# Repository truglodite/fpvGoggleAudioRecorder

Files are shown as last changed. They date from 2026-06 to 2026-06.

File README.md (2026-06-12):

# fpvGoggleAudioRecorder
## A reliable audio recording device for FPV goggles

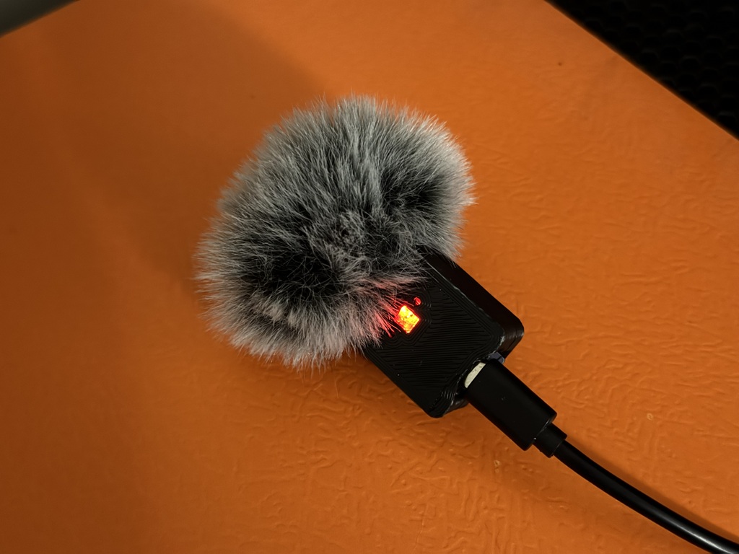
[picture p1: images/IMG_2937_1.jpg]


This is code for a plug and forget ambient audio recorder, intended for use with FPV goggles (like DJI goggles).

### Hardware:
*No pins installed if using the printable enclosure*
- Waveshare RP2040 Zero: https://www.amazon.com/DWEII-RP2040-Zero-Microcontroller-Development-MicroPython/dp/B0C5Q2V49P
- ICS43434 I2S Microphone: https://www.amazon.com/ICS43434-Microphone-Breakout-Module-Filter/dp/B0FMDGRM8F
- Micro SD Card Breakout (3.3V): https://www.amazon.com/WWZMDiB-Module-Adapter-Memory-Shield/dp/B0BV8ZQ81F
- 6mm Momentary NO Tactile Button: https://www.amazon.com/Momentary-Tactile-Through-Breadboard-Friendly/dp/B07WF76VHT

* Note that an INMP441 mic could be used in place of the ICS43434 if needed, but audio quality is not quite as good. Also the printed enclosure only fits the ICS mic.

### Operation
Simply plug in USB power, and the system will start to record. Unplug USB to stop the recording. If you need to start a new file during a recording session, hit the button, a blue LED will flash, and a new file will be started. This can be useful if for example you wait a while for GPS before launching, hit the button so you have an audio file that starts just before launching.

When powering on, you should first see a blue LED to indicate boot status followed by a pulsating green LED to indicate normal recording, and with an occasional red flash during louder noises to indicate the clipping limiter is active. If you see just a repeating flashing red led, the SD card is failing. If you see an orange flashing LED, the audio buffer is falling behind.

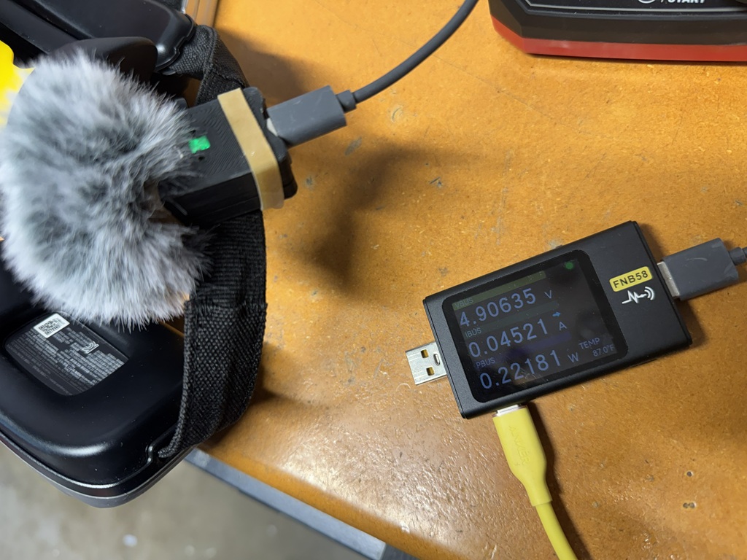
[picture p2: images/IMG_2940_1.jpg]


The goggle battery should be more than adequate even for very long flying sessions. The circuit draws only ~50mA while recording.

### Recording Format:
Similar to how a dashcam/bodycam works, this code records audio to raw PCM files with routines that prevent data corruption when power is suddenly lost while recording. When power is cutoff, only the last seconds of the recording session will be lost. The files are named "rec_X-Y.raw", where X is the recording session, and Y is the audio segment. Both X and Y increment to allow easy reconstruction of wav files. The "manifest.txt" file keeps a log of segments that have been saved, as well as segments that were lost due to power cutoff. The newest segments will be at the top of the manifest file.

The code makes use of an RMS audio compressor with smooth clipping that has been somewhat optimized for the hardware and intended application. Voices and noises farther away will have a similar volume to the voice of the person wearing the mic. Due to "aggressive AGC parameters", there will be some noise underlying the audio, but it is minimal. The audio performance with the ICS43434 using approach results much higher quality audio compared to the usual MAX9815+ADC setup.

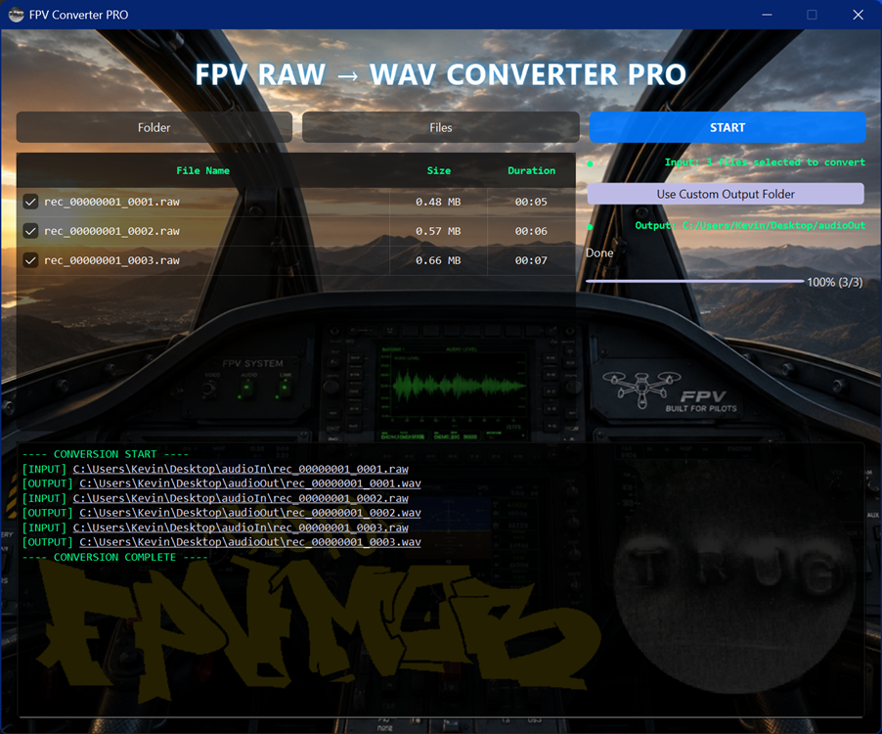
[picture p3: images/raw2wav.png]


For convenience I created `raw2wav.exe`, a Windows executable that converts raw files recorded with the fpvGoggleAudioRecorder into easy to use wav files (raw2wav.exe, in raw2wav/dist/). To use the converter, run the `raw2wav.exe`, select the input folder (your SD card) and optionally an output folder. If any of the loaded files do not need conversion, uncheck the box next to them in the file selector area. Click the "Start" button to convert the selected files. The log area near the bottom shows which files are being converted and where the converted files are saved. You can click an output path in the log area to open the output folder in explorer.

Alternatively, you can use an audio editing program like Audacity to "import raw data", with "little endian" and "44000" bit rate, and export a wav file.

### Flashing/Compiling:
To flash your RP2040 with the included firmware (`.pio/build/pico/firmware.uf2`), hold the boot button then press/release the reset button to put the board into flashing mode. The RP2040 should show up as a mass storage device in explorer. Simply copy `firmware.uf2` to the root of the RP2040, and reboot.

If you would like to customize the code, you should import this repo to PlatformIO. The maxgerhardt raspi platform, the earlephilhower pico core, and the Adafruit NeoPixel library are required for compiling.

https://github.com/maxgerhardt/platform-raspberrypi.git
https://github.com/earlephilhower/arduino-pico

### Wiring:
Connect the hardware as shown in the table below. The button is optional for manual recording variants, and is not required for autorecording.

Device  |   Pin |   RP2040 Pin
----|-----|----
MIC |   SEL |   GND
MIC |   LRCL |   11
MIC |   DOUT |   12
MIC |   BCLK |   10
MIC |   GND |   GND
MIC |   3V |   3v3
SD |   GND |   GND
SD |   MISO |   4
SD |   CLK |   2
SD |   MOSI |   3
SD |   CS |   5
SD |    3v3 |   3v3
BUTT |   A/B |   6/GND

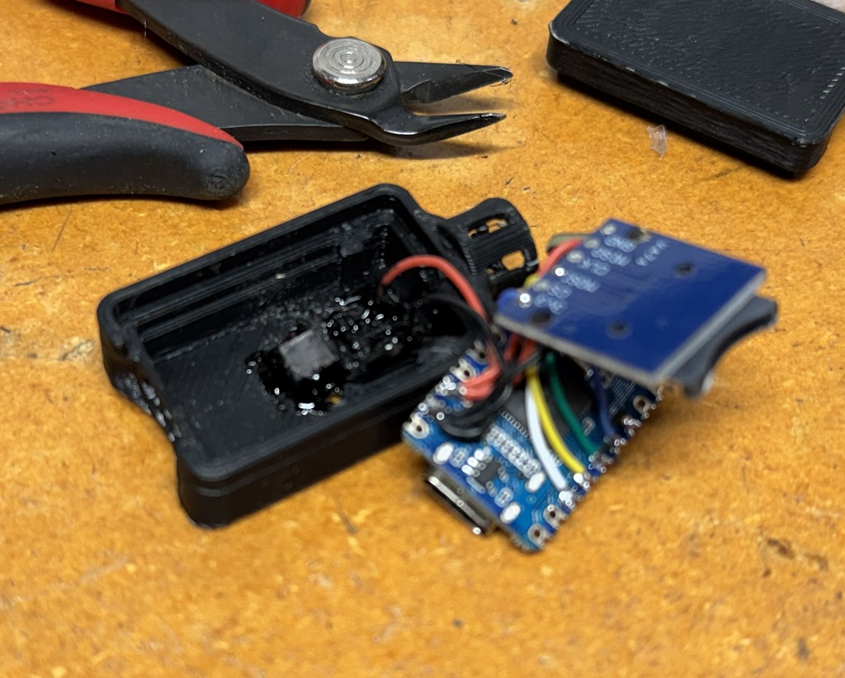
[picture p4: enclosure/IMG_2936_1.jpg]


### Printable Enclosure:
Files for a printable enclosure are provided in this repo. One of each part should be printed. Print the "agcRecorderTopWindscreen.stl" if you want to use a 10mm foam or furry cover for the mic. ABS or PETG is recommended for the top, bottom, and shim. Clear PETG filament should be used for the lens. Some glue is needed for a durable assembly; I used T-7000 glue on all of the joints described below.

To assemble the enclosure, first test fit your button, boards, and mic in the enclosure top/bottom. The mic is oriented with pin holes toward the top, with the mic hole facing out the side with the hole in it. The RP2040 is inserted with buttons facing the top, USB out the side. The button is rotated with pin sides facing the mic/usb sides of the enclosure. The SD card board is placed with the metal card insert part facing toward the top. First insert the lens, button, and mic in the top half, then insert the RP2040 board. Insert the SD board in the bottom half. Place the board shim over the RP2040 processor, and press the bottom half onto the top half. There are tabs for a click fit between the top/bottom halves. When assembled, verify the button protrudes out the top enough for easy operation, the SD card is easy to insert/remove, USB cable is easy to get to, and the case halves close completely. There should be an even 1mm gap around the edge where the top/bottom halves fit together. Also make sure you can fit a paper clip or similar rod through the Boot/Reset button access holes located near the lens.

The enclosure is very compact; 30awg silicone wire or smaller is recommended. Make all wires long enough to reach when assembled, but not so long that assembly can pinch a wire. Leave enough length on the SD card wires so the enclosure halves can easily be assembled/disassembled. Solder wires for the button and add heatshrink; break off the unused pins from the other side of the button. Solder wires to the chip side of the microphone. Solder wires to the back side (opposite of boot/reset buttons) on the RP2040. When wires are all soldered, glue the button into place taking care not to allow glue to squirt where it may interfere with operation. Glue the lens into the top half of the case. Add glue to the rails where the RP2040 and SD card boards will rest, and insert the components into the case halves. Snap case halves together taking care not to pinch any wires. Add the windscreen cover if desired; some glue around the bottom of the windstopper basket where it touches the box will offer a more reliable hold.

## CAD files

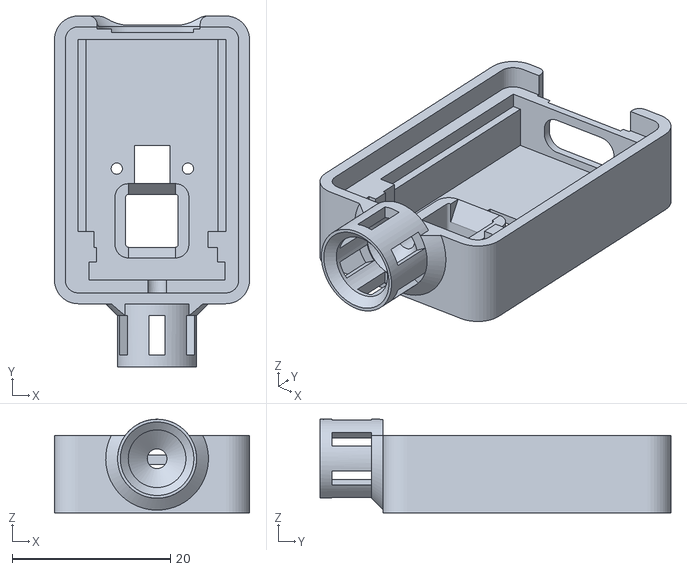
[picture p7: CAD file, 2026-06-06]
enclosure/agcRecorderTopWindscreen.stl
24.7 x 44.4 x 11.8

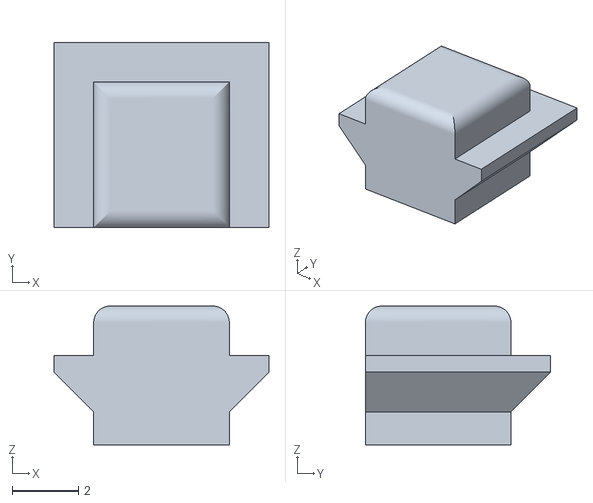
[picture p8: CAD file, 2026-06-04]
enclosure/agcRecorderLens.stl
6.50 x 5.60 x 4.20

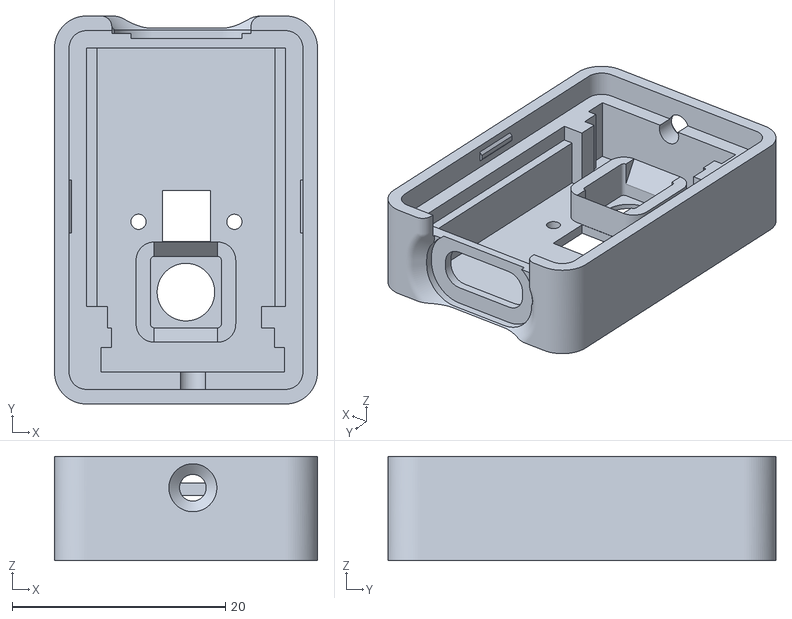
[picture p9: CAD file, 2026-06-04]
enclosure/agcRecordertop.stl
24.7 x 36.4 x 9.79

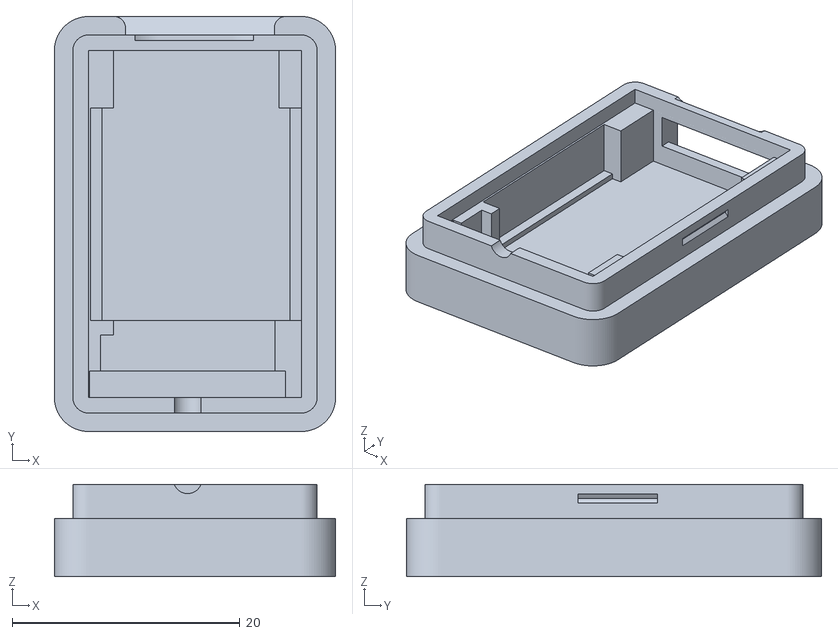
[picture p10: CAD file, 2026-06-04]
enclosure/agcRecorderBottom.stl
24.7 x 36.4 x 8.08

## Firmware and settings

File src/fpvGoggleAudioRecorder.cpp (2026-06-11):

/*
    fpvGoggleAudioRecorder.cpp
    Production-oriented FPV goggle audio recorder

    Hardware:
    - Waveshare RP2040 Zero
    - ICS43434 I2S microphone
    - SPI microSD
    - Momentary Segment Button on GPIO 6 (Active Low, Internal Pullup)

    Features:
    - Dual-core audio pipeline
    - Large ring buffer
    - Crash-resistant segmented recording
    - SD write retries
    - Core1 heartbeat monitoring
    - I2S timeout recovery
    - Queue synchronization barriers
    - Disk full detection
    - Watchdog recovery
    - Non-blocking LED updates with visual button feedback
    - Instant power-on recording
    - Manual file split / start new file button (GPIO 6)

    Audio:
    - RAW PCM
    - Signed 16-bit little endian
    - 44100 Hz mono

    Requires:
    - Arduino-Pico (Earle Philhower)
*/

#include <Arduino.h>
#include <SPI.h>
#include <SD.h>
#include <I2S.h>
#include <Adafruit_NeoPixel.h>

#include "pico/multicore.h"
#include "hardware/watchdog.h"
#include "hardware/sync.h"

#include <math.h>

// ======================================================
// CONFIG
// ======================================================

#define SAMPLE_RATE            44100

#define BLOCK_SAMPLES          256
#define QUEUE_BLOCKS           128

#define SEGMENT_MS             120000UL
#define FLUSH_INTERVAL_MS      1000UL

#define SD_CS                  5
#define LED_PIN                16
#define BUTTON_PIN             6  // New File / Split Button on GPIO 6

#define I2S_DATA_PIN           12
#define I2S_BCLK_PIN           10

#define WATCHDOG_TIMEOUT_MS    4000
#define CORE1_TIMEOUT_MS       2000

#define MEMORY_BARRIER()       __dmb()

// ======================================================
// LED
// ======================================================

Adafruit_NeoPixel led(
    1,
    LED_PIN,
    NEO_GRB + NEO_KHZ800
);

enum LedMode
{
    LED_BOOT,
    LED_RECORDING,
    LED_SD_WARN,
    LED_BUFFER_WARN,
    LED_FATAL,
    LED_BUTTON_SPLIT // Added: State for button press feedback
};

volatile LedMode ledMode = LED_BOOT;
volatile uint32_t buttonFeedbackStartMs = 0; // Tracks when the blue LED turned on

// ======================================================
// SHARED STATE
// ======================================================

volatile uint16_t globalPeak = 0;
volatile uint32_t lastAudioMs = 0;

volatile uint32_t core1Heartbeat = 0;

volatile bool fatalState = false;
volatile bool sdWarning = false;
volatile bool bufferWarning = false;
volatile bool diskFull = false;

volatile bool recording = false;
volatile bool rolloverPending = false;
volatile bool limiterActive = false;

// ======================================================
// I2S
// ======================================================

I2S i2s(INPUT);

// ======================================================
// AUDIO BUFFER
// ======================================================

enum BlockState : uint8_t
{
    BLOCK_FREE = 0,
    BLOCK_FILLED = 1
};

struct AudioBlock
{
    int16_t samples[BLOCK_SAMPLES];
    volatile BlockState state;
};

AudioBlock queueBuffer[QUEUE_BLOCKS];

volatile uint16_t writeIndex = 0;
volatile uint16_t readIndex  = 0;

// ======================================================
// FILES
// ======================================================

File audioFile;
File manifestFile;

char currentFilename[64];

uint32_t sessionId = 0;
uint32_t segmentId = 0;

// ======================================================
// SYSTEM HEALTH
// ======================================================

struct SystemHealth
{
    volatile uint32_t bufferOverruns = 0;
    volatile uint32_t i2sTimeouts    = 0;
    volatile uint32_t sdErrors       = 0;
    volatile uint32_t writes         = 0;
};

SystemHealth sys;

// ======================================================
// LED HELPERS
// ======================================================

void setLED(
    uint8_t r,
    uint8_t g,
    uint8_t b
)
{
    led.setPixelColor(
        0,
        led.Color(r, g, b)
    );

    led.show();
}

void updateLedState()
{
    if (fatalState)
    {
        ledMode = LED_FATAL;
        return;
    }

    if (diskFull)
    {
        ledMode = LED_FATAL;
        return;
    }

    // Prioritize showing the blue button flash if it's currently active
    if (ledMode == LED_BUTTON_SPLIT)
    {
        if ((millis() - buttonFeedbackStartMs) < 500) 
        {
            return; // Stay in blue flash mode for 500ms
        }
    }

    if (sdWarning)
    {
        ledMode = LED_SD_WARN;
        return;
    }

    if (bufferWarning)
    {
        ledMode = LED_BUFFER_WARN;
        return;
    }

    ledMode = LED_RECORDING;
}

void updateLED()
{
    static uint32_t lastUpdate = 0;

    if ((millis() - lastUpdate) < 50)
        return;

    lastUpdate = millis();

    switch (ledMode)
    {
        case LED_BOOT:
        {
            setLED(0, 0, 40);
            break;
        }

        case LED_FATAL:
        {
            static bool blink = false;

            blink = !blink;

            if (blink)
                setLED(0, 100, 0);
            else
                setLED(0, 0, 0);

            break;
        }

        case LED_SD_WARN:
        {
            static bool blink = false;

            blink = !blink;

            if (blink)
                setLED(0, 80, 0);
            else
                setLED(0, 0, 0);

            break;
        }

        case LED_BUFFER_WARN:
        {
            static bool blink = false;

            blink = !blink;

            if (blink)
                setLED(40, 80, 0);
            else
                setLED(0, 0, 0);

            break;
        }

        case LED_BUTTON_SPLIT:
        {
            // Turn LED Solid Blue for file split confirmation
            setLED(0, 0, 120); 
            break;
        }

        case LED_RECORDING:
        {
            bool active =
                (
                    millis() -
                    lastAudioMs
                ) < 250;

            if (!active)
            {
                setLED(
                    0,
                    2,
                    0
                );
            }
            else
            {
                uint8_t level =
                    constrain(
                        map(
                            globalPeak,
                            0,
                            16000,
                            2,
                            80
                        ),
                        2,
                        80
                    );

                // Clip indicator
                if (
                    limiterActive
                )
                {
                    setLED(
                        0,
                        80,
                        0
                    );
                }
                else
                {
                    // Audio level meter
                    setLED(
                        level,
                        0,
                        0
                    );
                }
            }

            break;
        }
    }
}

// ======================================================
// FATAL HANDLER
// ======================================================

void fatalError()
{
    fatalState = true;

    while (1)
    {
        updateLedState();
        updateLED();

        // intentionally do NOT feed watchdog

        delay(10);
    }
}
// ======================================================
// MANIFEST
// ======================================================

void openManifest()
{
    manifestFile = SD.open(
        "/manifest.log",
        FILE_WRITE
    );

    if (!manifestFile)
        fatalError();

    manifestFile.print("SESSION_START,");
    manifestFile.println(millis());

    manifestFile.flush();
}

void logEvent(
    const char *type,
    const char *name
)
{
    if (!manifestFile)
        return;

    manifestFile.print(type);
    manifestFile.print(",");
    manifestFile.print(name);
    manifestFile.print(",");
    manifestFile.println(millis());

    manifestFile.flush();
}

// ======================================================
// SESSION COUNTER
// ======================================================

uint32_t loadSessionCounter()
{
    uint32_t id = 0;

    File f = SD.open(
        "/session.dat",
        FILE_READ
    );

    if (f)
    {
        if (f.available() >= sizeof(id))
        {
            f.read(
                (uint8_t *)&id,
                sizeof(id)
            );
        }

        f.close();
    }

    id++;

    f = SD.open(
        "/session.dat",
        FILE_WRITE
    );

    if (f)
    {
        f.seek(0);

        f.write(
            (uint8_t *)&id,
            sizeof(id)
        );

        f.flush();
        f.close();
    }

    return id;
}

// ======================================================
// SEGMENT MANAGEMENT
// ======================================================

void openSegment()
{
    segmentId++;

    snprintf(
        currentFilename,
        sizeof(currentFilename),
        "/rec_%08lu_%04lu.raw",
        (unsigned long)sessionId,
        (unsigned long)segmentId
    );

    audioFile = SD.open(
        currentFilename,
        FILE_WRITE
    );

    if (!audioFile)
        fatalError();

    logEvent(
        "OPEN",
        currentFilename
    );
}

void closeSegment()
{
    if (!audioFile)
        return;

    audioFile.flush();
    audioFile.close();

    logEvent(
        "CLOSE",
        currentFilename
    );
}

// ======================================================
// QUEUE HELPERS
// ======================================================

bool queueEmpty()
{
    for (int i = 0; i < QUEUE_BLOCKS; i++)
    {
        if (
            queueBuffer[i].state ==
            BLOCK_FILLED
        )
        {
            return false;
        }
    }

    return true;
}

uint32_t queueUsed()
{
    uint32_t count = 0;

    for (int i = 0; i < QUEUE_BLOCKS; i++)
    {
        if (
            queueBuffer[i].state ==
            BLOCK_FILLED
        )
        {
            count++;
        }
    }

    return count;
}

// ======================================================
// DSP STATE
// ======================================================

struct DSPState
{
    float hp;
    float prev;
    float env;
};

DSPState dsp =
{
    0.0f,
    0.0f,
    0.0f
};

// ======================================================
// DSP
// ======================================================

inline int16_t processSample(
    int32_t sample
)
{
    float x =
        (float)(sample >> 8);

    // ----------------------------------
    // DC blocker
    // ----------------------------------

    dsp.hp =
        0.995f * dsp.hp +
        x -
        dsp.prev;

    dsp.prev = x;

    x = dsp.hp;

    // ----------------------------------
    // Envelope tracker
    // ----------------------------------

    float absx = fabsf(x);

    if (absx > dsp.env)
    {
        dsp.env = absx;
    }
    else
    {
        dsp.env *= 0.9997f;
    }

    // ----------------------------------
    // Soft limiter
    // ----------------------------------

    const float limit = 14000.0f;

    limiterActive =
        false;

    if (
        dsp.env >
        limit
    )
    {
        limiterActive =
            true;

        x *=
        (
            limit /
            dsp.env
        );
    }

    // ----------------------------------
    // Clamp
    // ----------------------------------

    if (x > 32767.0f)
        x = 32767.0f;

    if (x < -32768.0f)
        x = -32768.0f;

    return (int16_t)x;
}

// ======================================================
// PEAK TRACKER
// ======================================================

inline void updatePeak(
    int16_t sample
)
{
    uint16_t a =
        abs(sample);

    uint16_t peak =
        globalPeak;

    if (a > peak)
    {
        globalPeak = a;
    }
    else if (peak > 0)
    {
        globalPeak = peak - 1;
    }
}

// ======================================================
// SELF TEST
// ======================================================

bool runSelfTest()
{
    File f =
        SD.open(
            "/selftest.tmp",
            FILE_WRITE
        );

    if (!f)
        return false;

    uint8_t x = 0x55;

    bool ok =
        (
            f.write(&x, 1)
            ==
            1
        );

    f.close();

    SD.remove(
        "/selftest.tmp"
    );

    return ok;
}
// ======================================================
// AUDIO CORE (CORE 1)
// ======================================================

void audioCore()
{
    int32_t left = 0;
    int32_t right = 0;

    while (1)
    {
        // ---------------------------------
        // Wait for recording enable
        // ---------------------------------

        if (!recording)
        {
            delay(1);
            continue;
        }

        // ---------------------------------
        // Heartbeat
        // ---------------------------------

        core1Heartbeat = millis();

        // ---------------------------------
        // Acquire current block
        // ---------------------------------

        AudioBlock &block =
            queueBuffer[writeIndex];

        // ---------------------------------
        // Queue full?
        // ---------------------------------

        if (
            block.state ==
            BLOCK_FILLED
        )
        {
            sys.bufferOverruns++;

            bufferWarning = true;

            delayMicroseconds(100);

            continue;
        }

        // ---------------------------------
        // Fill block
        // ---------------------------------

        for (
            int i = 0;
            i < BLOCK_SAMPLES;
            i++
        )
        {
            uint32_t startUs =
                micros();

            bool gotSample =
                false;

            // -----------------------------
            // Wait for I2S
            // -----------------------------

            while (!i2s.available())
            {
                if (
                    micros() - startUs
                    >
                    5000
                )
                {
                    sys.i2sTimeouts++;

                    break;
                }
            }

            // -----------------------------
            // Read sample if available
            // -----------------------------

            if (i2s.available())
            {
                i2s.read(
                    &left,
                    &right
                );

                gotSample = true;
            }

            // -----------------------------
            // Timeout fallback
            // -----------------------------

            if (!gotSample)
            {
                left = 0;
                right = 0;
            }

            // -----------------------------
            // Process sample
            // -----------------------------

            int16_t pcm =
                processSample(left);

            block.samples[i] =
                pcm;

            updatePeak(pcm);
        }

        // ---------------------------------
        // Publish block safely
        // ---------------------------------

        MEMORY_BARRIER();

        block.state =
            BLOCK_FILLED;

        MEMORY_BARRIER();

        writeIndex++;

        if (
            writeIndex >=
            QUEUE_BLOCKS
        )
        {
            writeIndex = 0;
        }

        lastAudioMs =
            millis();

        // ---------------------------------
        // Clear warning if queue healthy
        // ---------------------------------

        uint32_t used =
            queueUsed();

        if (
            used <
            (QUEUE_BLOCKS / 2)
        )
        {
            bufferWarning = false;
        }
    }
}
// ======================================================
// SD WRITE HELPERS
// ======================================================

bool writeAudioBlock(
    AudioBlock &block
)
{
    const size_t expected =
        sizeof(block.samples);

    size_t bytes = 0;

    for (
        int retry = 0;
        retry < 3;
        retry++
    )
    {
        bytes =
            audioFile.write(
                (uint8_t *)block.samples,
                expected
            );

        if (bytes == expected)
        {
            return true;
        }

        delay(2);
    }

    return false;
}

// ======================================================
// WRITER TASK
// ======================================================

void writeTaskStep()
{
    static uint32_t lastFlush = 0;

    // ---------------------------------
    // Current queue block
    // ---------------------------------

    AudioBlock &block =
        queueBuffer[readIndex];

    // ---------------------------------
    // No work
    // ---------------------------------

    if (
        block.state !=
        BLOCK_FILLED
    )
    {
        // -----------------------------
        // Handle rollover only after
        // queue fully drained
        // -----------------------------

        if (
            rolloverPending &&
            queueEmpty()
        )
        {
            if (audioFile)
            {
                audioFile.flush();
            }

            closeSegment();
            openSegment();

            rolloverPending = false;
        }

        return;
    }

    // ---------------------------------
    // SD write
    // ---------------------------------

    bool ok =
        writeAudioBlock(
            block
        );

    if (!ok)
    {
        sys.sdErrors++;

        sdWarning = true;

        if (
            sys.sdErrors > 10
        )
        {
            diskFull = true;
        }
    }
    else
    {
        sys.writes++;

        if (
            sys.sdErrors == 0
        )
        {
            sdWarning = false;
        }
    }

    // ---------------------------------
    // Release queue block
    // ---------------------------------

    MEMORY_BARRIER();

    block.state =
        BLOCK_FREE;

    MEMORY_BARRIER();

    readIndex++;

    if (
        readIndex >=
        QUEUE_BLOCKS
    )
    {
        readIndex = 0;
    }

    // ---------------------------------
    // Periodic flush
    // ---------------------------------

    if (
        millis() -
        lastFlush
        >
        FLUSH_INTERVAL_MS
    )
    {
        if (audioFile)
        {
            audioFile.flush();
        }

        if (manifestFile)
        {
            manifestFile.flush();
        }

        lastFlush =
            millis();
    }

    // ---------------------------------
    // Segment rollover
    // ---------------------------------

    if (
        rolloverPending &&
        queueEmpty()
    )
    {
        if (audioFile)
        {
            audioFile.flush();
        }

        closeSegment();
        openSegment();

        rolloverPending = false;
    }
}

// ======================================================
// STATUS LOGGER
// ======================================================

void printStats()
{
    static uint32_t lastPrint = 0;

    if (
        millis() -
        lastPrint
        <
        5000
    )
    {
        return;
    }

    lastPrint = millis();

    Serial.print("writes=");
    Serial.print(sys.writes);

    Serial.print(" overruns=");
    Serial.print(sys.bufferOverruns);

    Serial.print(" i2s=");
    Serial.print(sys.i2sTimeouts);

    Serial.print(" sd=");
    Serial.print(sys.sdErrors);

    Serial.print(" queued=");
    Serial.println(queueUsed());
}

// ======================================================
// SINGLE BUTTON FILE SPLITTER (NEW FILE COMMAND)
// ======================================================

void checkButton()
{
    static uint32_t lastDebounceTime = 0;
    static bool lastButtonState = HIGH;
    static bool buttonState = HIGH;

    bool reading = digitalRead(BUTTON_PIN);

    if (reading != lastButtonState) {
        lastDebounceTime = millis();
    }

    if ((millis() - lastDebounceTime) > 50) { 
        if (reading != buttonState) {
            buttonState = reading;

            // Button Pressed down to GND (Falling Edge)
            if (buttonState == LOW) {
                if (recording && !rolloverPending) {
                    Serial.println(">>> BUTTON PRESSED: FORCING NEW AUDIO FILE SEGMENT <<<");
                    
                    // Trigger blue LED state change
                    ledMode = LED_BUTTON_SPLIT;
                    buttonFeedbackStartMs = millis();
                    
                    rolloverPending = true; // Signals writeTaskStep to roll files cleanly
                    MEMORY_BARRIER();
                }
            }
        }
    }
    lastButtonState = reading;
}
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
void loop()
{
    // -----------------------------
    // watchdog feed
    // -----------------------------

    watchdog_update();

    // -----------------------------
    // button interaction scan
    // -----------------------------
    checkButton();

    // -----------------------------
    // writer task
    // -----------------------------

    writeTaskStep();

    // -----------------------------
    // LED state resolve
    // -----------------------------

    updateLedState();
    updateLED();

    // -----------------------------
    // health checks
    // -----------------------------

    checkCore1Health();
    checkDiskState();

    // -----------------------------
    // debug stats
    // -----------------------------

    printStats();

    // -----------------------------
    // yield
    // -----------------------------

    delay(1);
}

// ======================================================
// END OF FILE
// ======================================================

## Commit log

2026-06-04 Add stl files
    [agcRecorderBoardShim.stl, agcRecorderBottom.stl, agcRecorderLens.stl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]
2026-06-04 update readme w/ lens glue
2026-06-04 fix led and update readme
    [fpvGoggleAudioRecorder.cpp]
2026-06-06 added windscreen enclosure part, and enclosure images, updated readme
    [agcRecorderTopWindscreen.stl]
2026-06-06 readme, delete shim
    [agcRecorderBoardShim.stl]
2026-06-06 add sd 3v3 wiring to readme
2026-06-06 clarify button wiring in readme
2026-06-07 update led indicators and readme
2026-06-07 add wiring comments to code
2026-06-07 cut down wiring comments
2026-06-11 add button file separator feature, update readme, make new raw2wav converter.
